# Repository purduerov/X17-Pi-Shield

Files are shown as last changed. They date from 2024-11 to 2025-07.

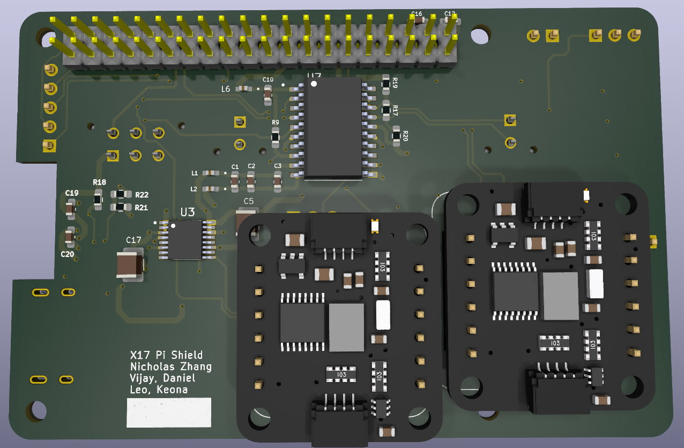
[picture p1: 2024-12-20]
Work Screenshots/3D_Back.png

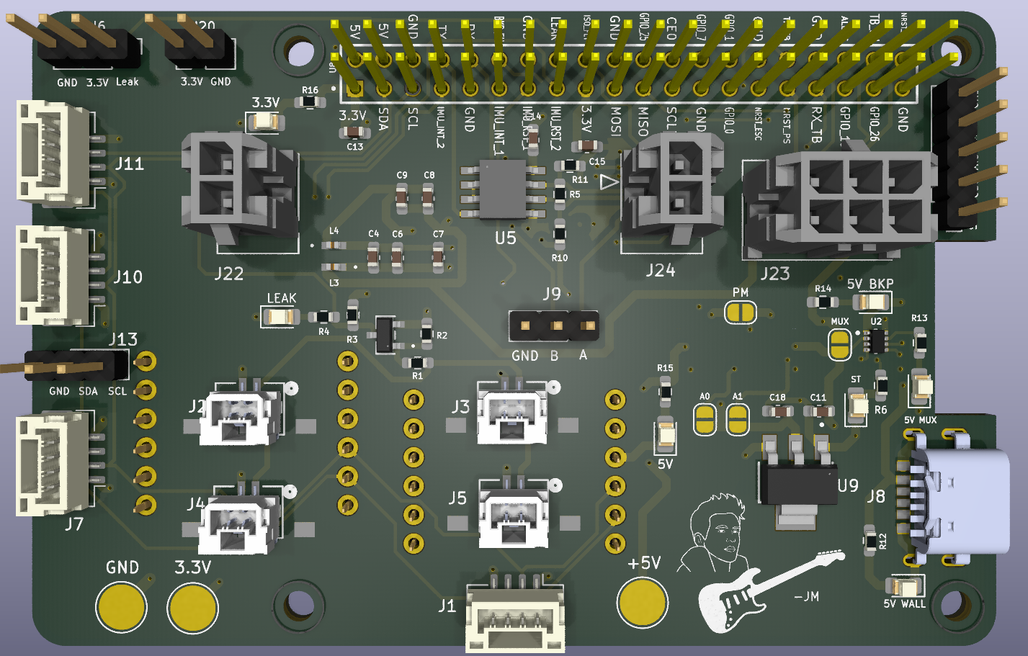
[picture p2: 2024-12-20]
Work Screenshots/3D_Front.png

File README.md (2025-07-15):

# X17-Pi-Shield
This board powers and connects sensors to the Pi

Whenever you make a new part, download the datasheet and save it here _**and**_ with the part in the parts library

Always pull other people's changes before beginning to work
`git pull`

Be sure to push your changes after  working on them. Run:
1. `git add .` to add any files in this directory or a subdirectory
or `git add -u` to add any modified files
2. (Optional) `git clean -nX` to see what ignored files can be removed
	`git clean -fX` removes ignored files (Eagle backups)
3. `git commit -m "helpful commit message"` with a description of the work that you did
4. `git push` to push your work to github

Other helpful commands
* `git status` says information about modified and staged files
* `git log` shows the recent commits of the repository
* `git log filename.extension` show the recent commits for just that file
* `git checkout first-couple-letter-of-commit-id` lets you go back to a previous version
* `git checkout master` brings you back to the latest commit
* `git tag` lists the tags
* `git tag -a orderX -m "the version of the board placed for the X'th order"` tag a specific commit
* `git push --tags` needed to push tags to remote
* `git show orderX` show the commit log for the given tag
* `git checkout orderX` go back and interact with the files at the tagged commit

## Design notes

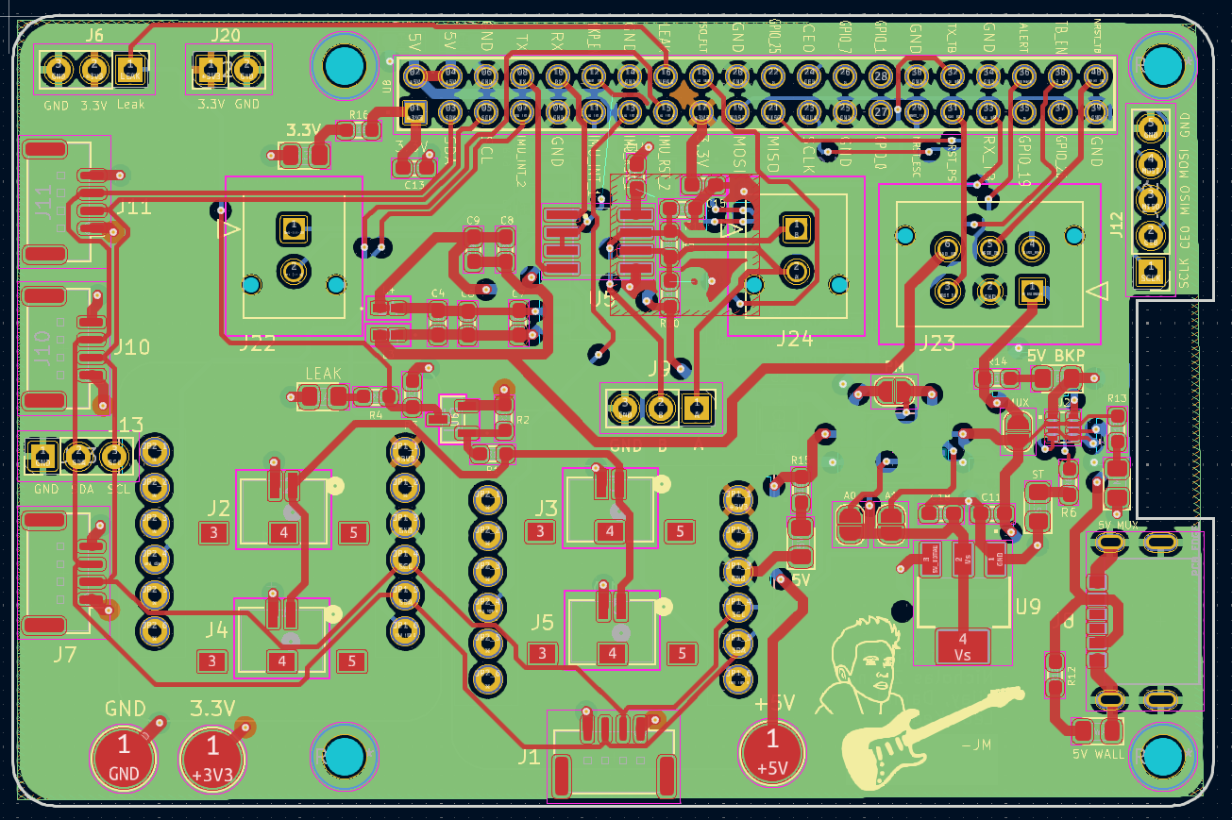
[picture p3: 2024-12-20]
Work Screenshots/Layout.png

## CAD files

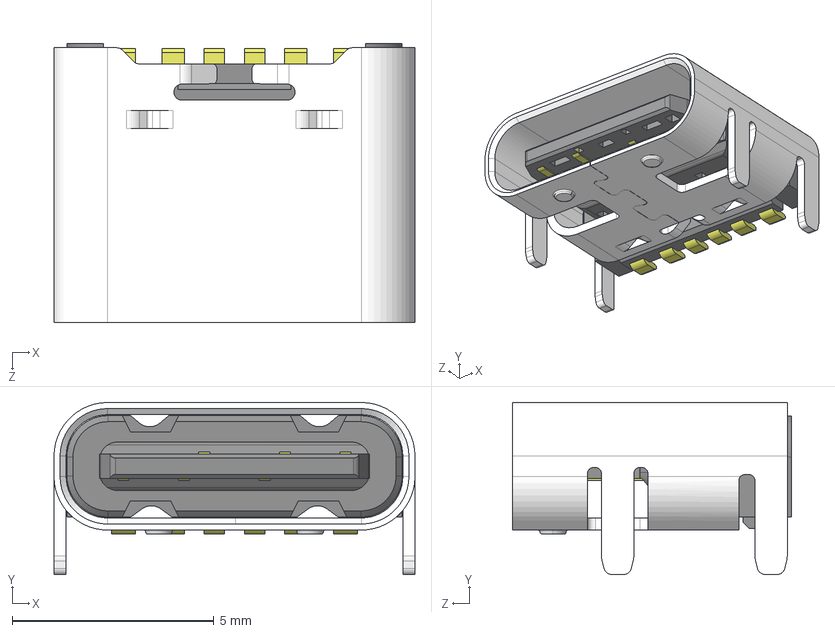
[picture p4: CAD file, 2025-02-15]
3D_MODELS/UJC-HP-3-SMT-TR.step
8.94 x 4.26 x 6.90 mm

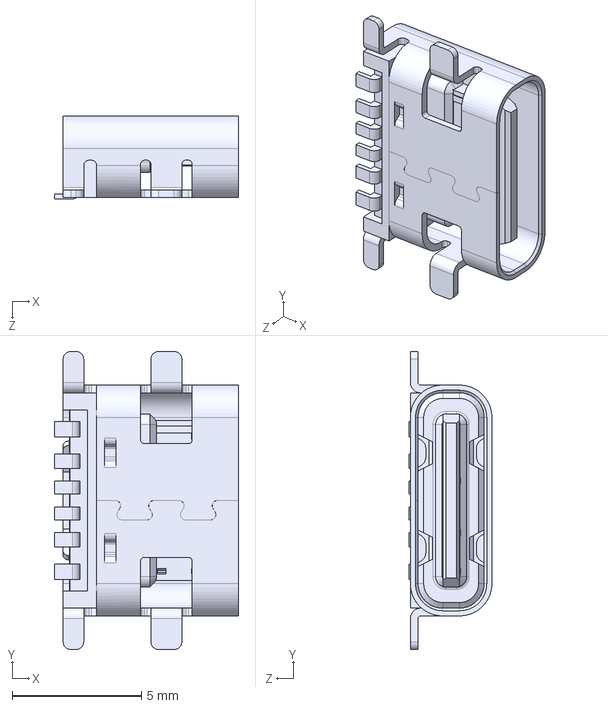
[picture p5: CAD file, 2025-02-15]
3D_MODELS/UJC-HP-G-5-SMT-TR.step
7.14 x 11.5 x 3.21 mm

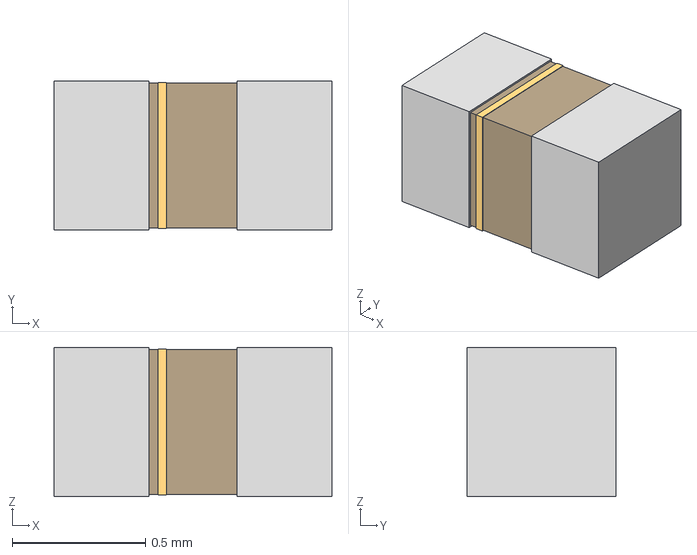
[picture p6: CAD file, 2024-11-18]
3D_MODELS/IND_BLM15_MUR.step
1.04 x 0.558 x 0.559 mm

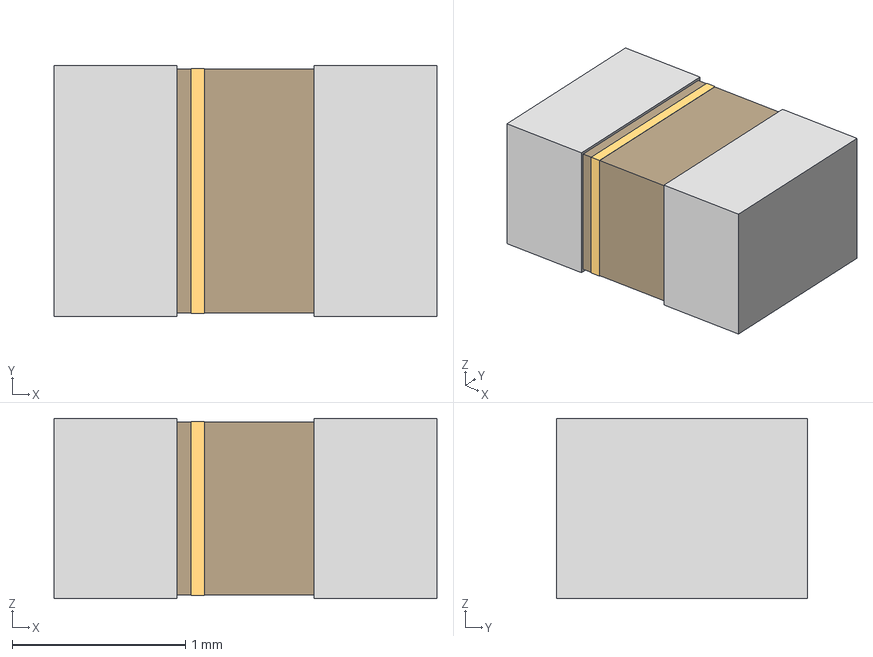
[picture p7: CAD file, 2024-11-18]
3D_MODELS/IND_BLM21_MUR.step
2.21 x 1.45 x 1.04 mm

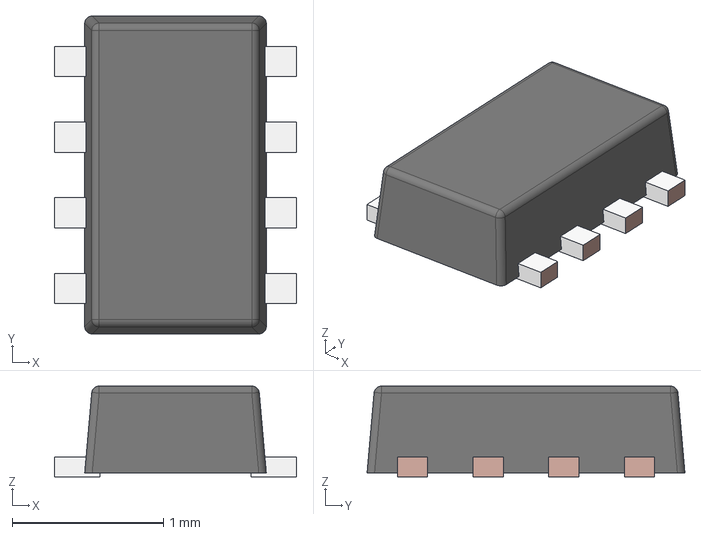
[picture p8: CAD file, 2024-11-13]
3D_MODELS/DRL0008A.stp
1.60 x 2.10 x 0.6 mm
FRAME-DRL0008A
BODY-SOT

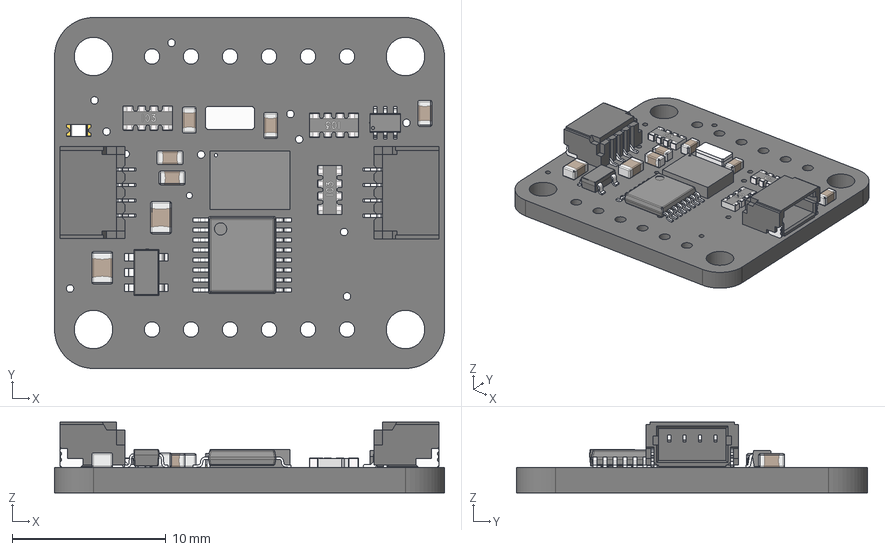
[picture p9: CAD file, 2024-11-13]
3D_MODELS/Adafruit BNO085 STEMMA QT.step
25.4 x 22.9 x 4.60 mm
Printed Circuit Board
BNO055-9axis-IMU
BNO085-9axis-IMU
BODY-TSSOP
LEAD-TSSOP x 16
Crystal_XTAL3215_32.768KHz
SOT23-5
BSS138PS
LED 0603 single color
CAPC-0805-T0.95-BN x 2
CAPC-0603-T0.9-BN x 5
YC164_RESPACK x 3
qwicc x 2

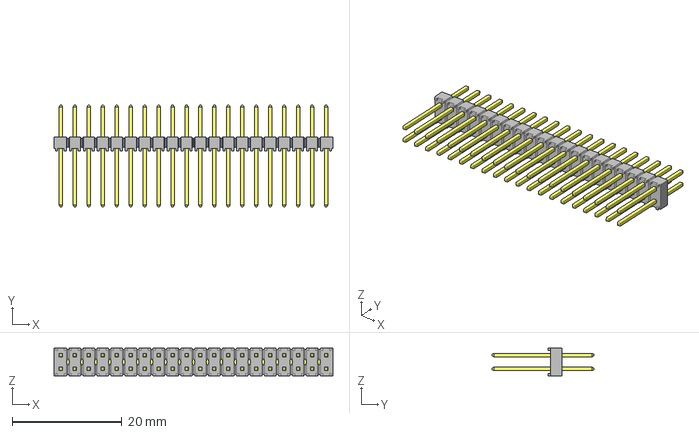
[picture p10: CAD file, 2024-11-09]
3D_MODELS/TSW-120-09-G-D.step
50.8 x 18.5 x 5.08 mm
TSW-120-09-G-D_body
T-1S6-09-TSW-1-09-20-D

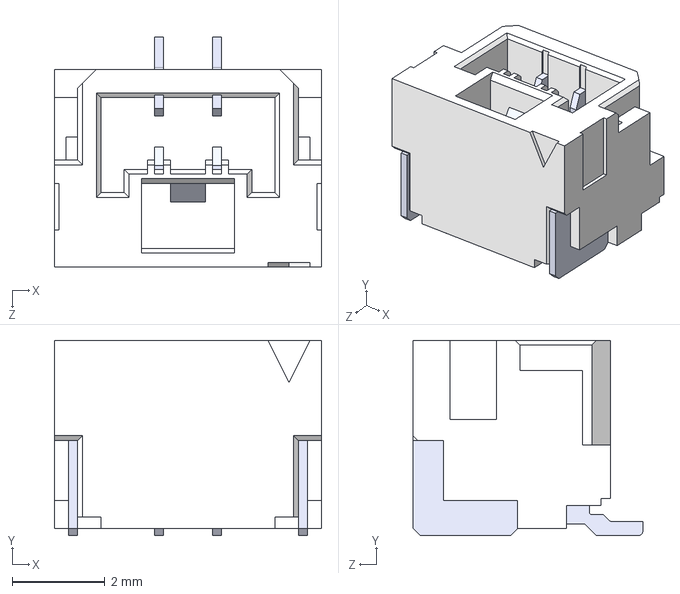
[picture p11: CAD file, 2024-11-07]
3D_MODELS/BM02B-GHS-TBT.STEP
5.75 x 4.20 x 4.95 mm

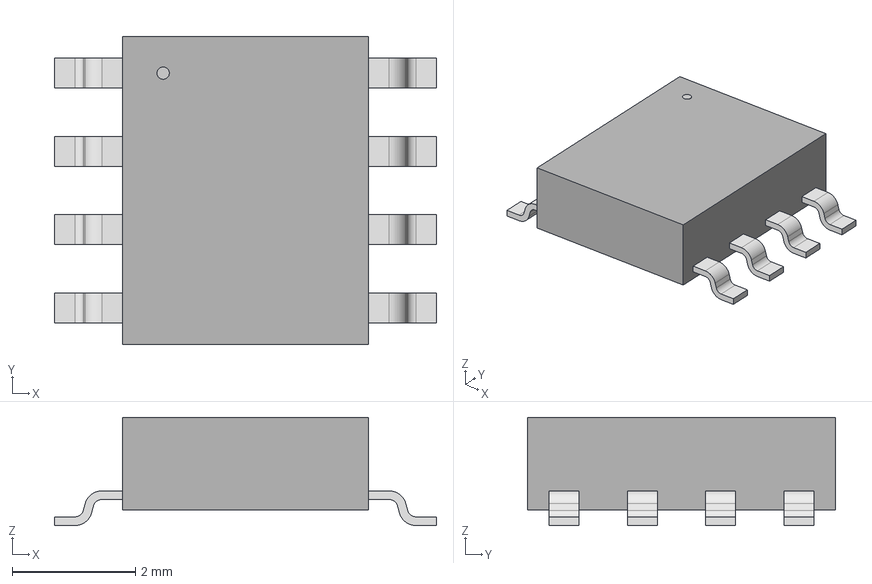
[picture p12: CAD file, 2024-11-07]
3D_MODELS/21-0041-3-M_90-0096-8L_MXM.step
6.20 x 5.00 x 1.75 mm

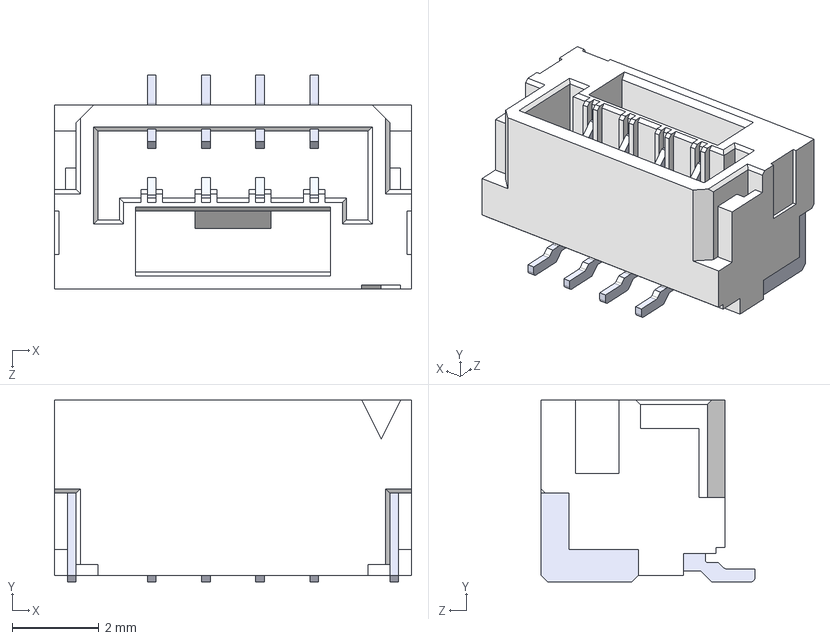
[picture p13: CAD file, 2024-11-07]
3D_MODELS/BM04B-GHS-TBT.step
8.25 x 4.20 x 4.95 mm

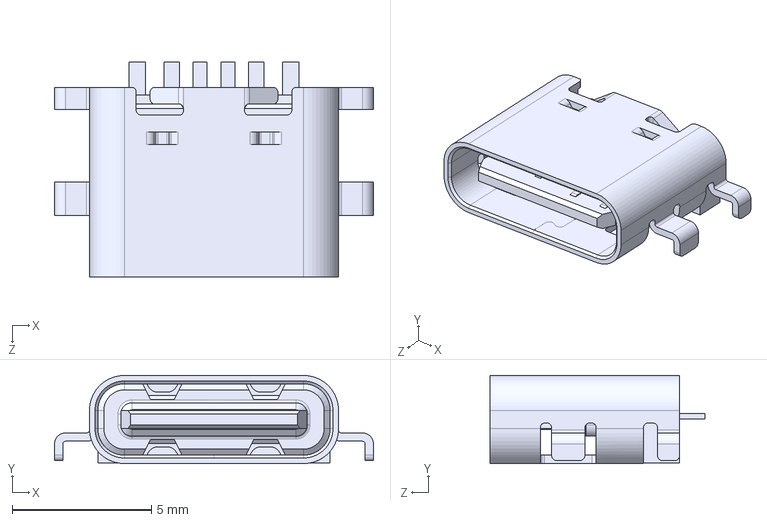
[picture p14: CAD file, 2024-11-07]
3D_MODELS/Same_Sky_UJC-HP-L-G-5-MSMT-TR.step
11.4 x 3.16 x 7.70 mm

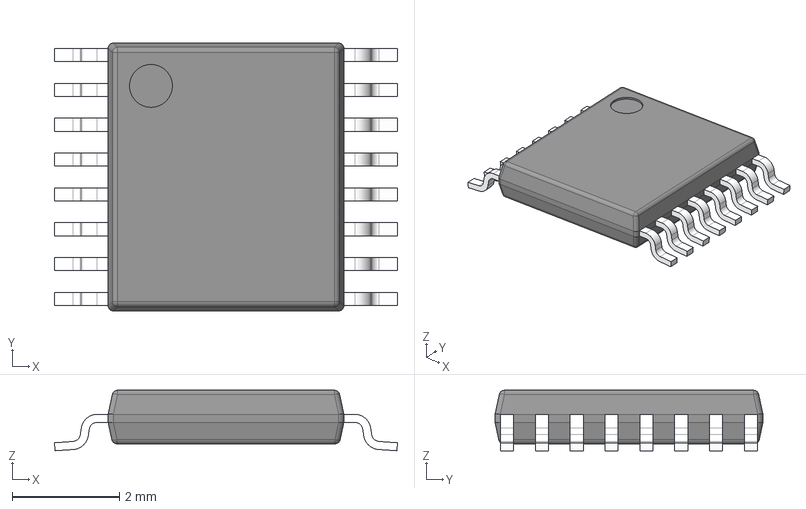
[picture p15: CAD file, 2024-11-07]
3D_MODELS/PW0016A.stp
6.40 x 5.00 x 1.13 mm
BODY-TSSOP
LEAD-TSSOP x 16
PIN1

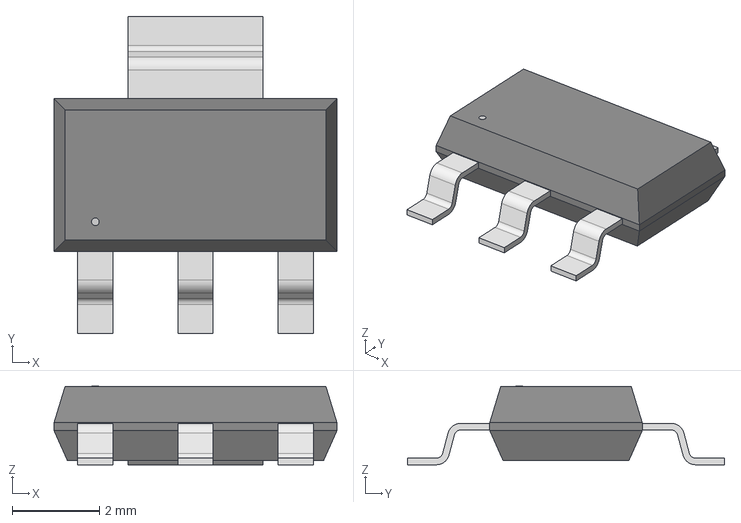
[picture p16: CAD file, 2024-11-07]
3D_MODELS/SOT223_AZ1117I_6P5X3P5_DIO.step
6.50 x 7.29 x 1.81 mm

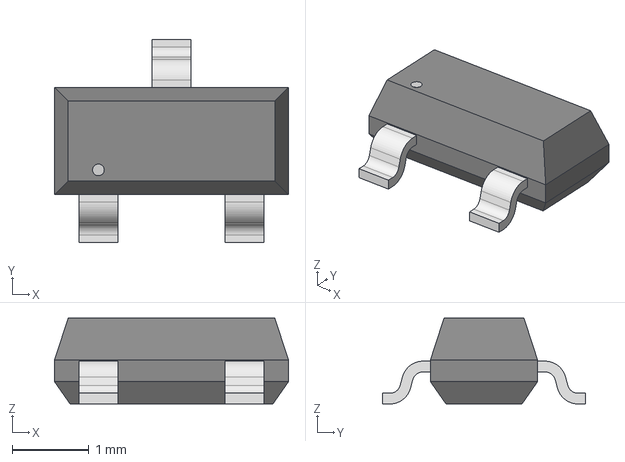
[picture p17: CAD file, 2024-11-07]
3D_MODELS/SOT-23-3_1P4X3P040_ONS.step
3.05 x 2.64 x 1.12 mm

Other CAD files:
3D_MODELS/ISOW1432BDFMR.step
3D_MODELS/INA260AIPW.step
3D_MODELS/430450212.stp
3D_MODELS/430450612.stp

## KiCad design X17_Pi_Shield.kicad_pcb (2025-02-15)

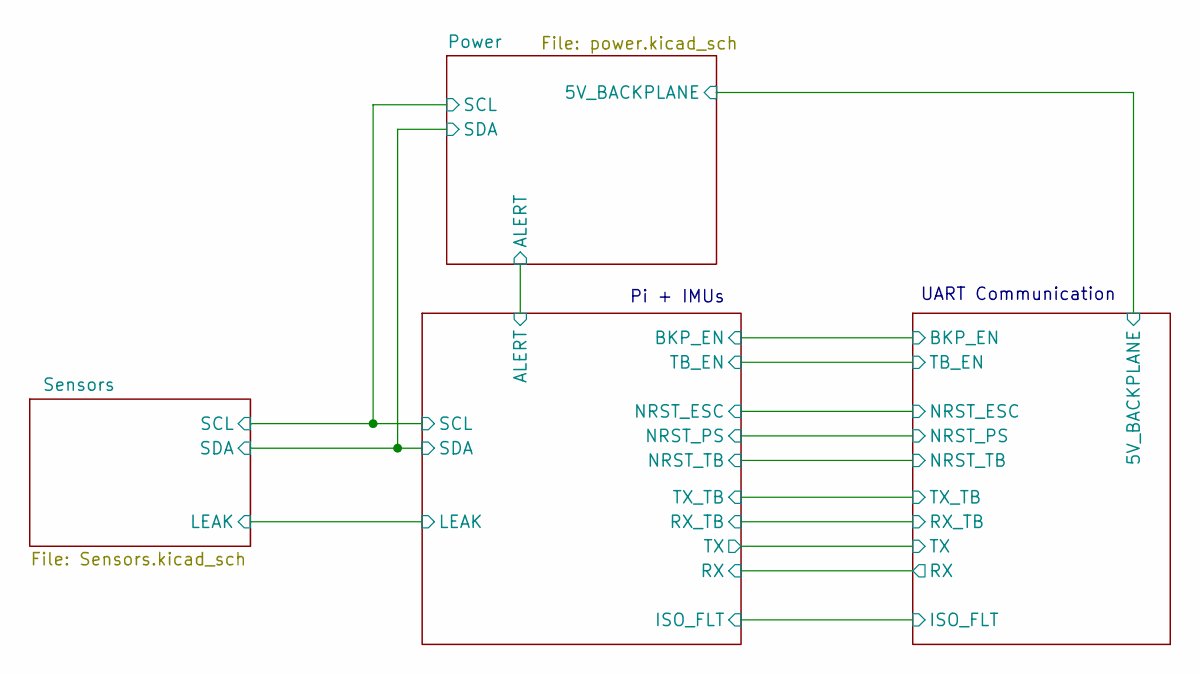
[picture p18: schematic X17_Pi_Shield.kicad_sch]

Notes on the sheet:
UART Communication
Pi + IMUs

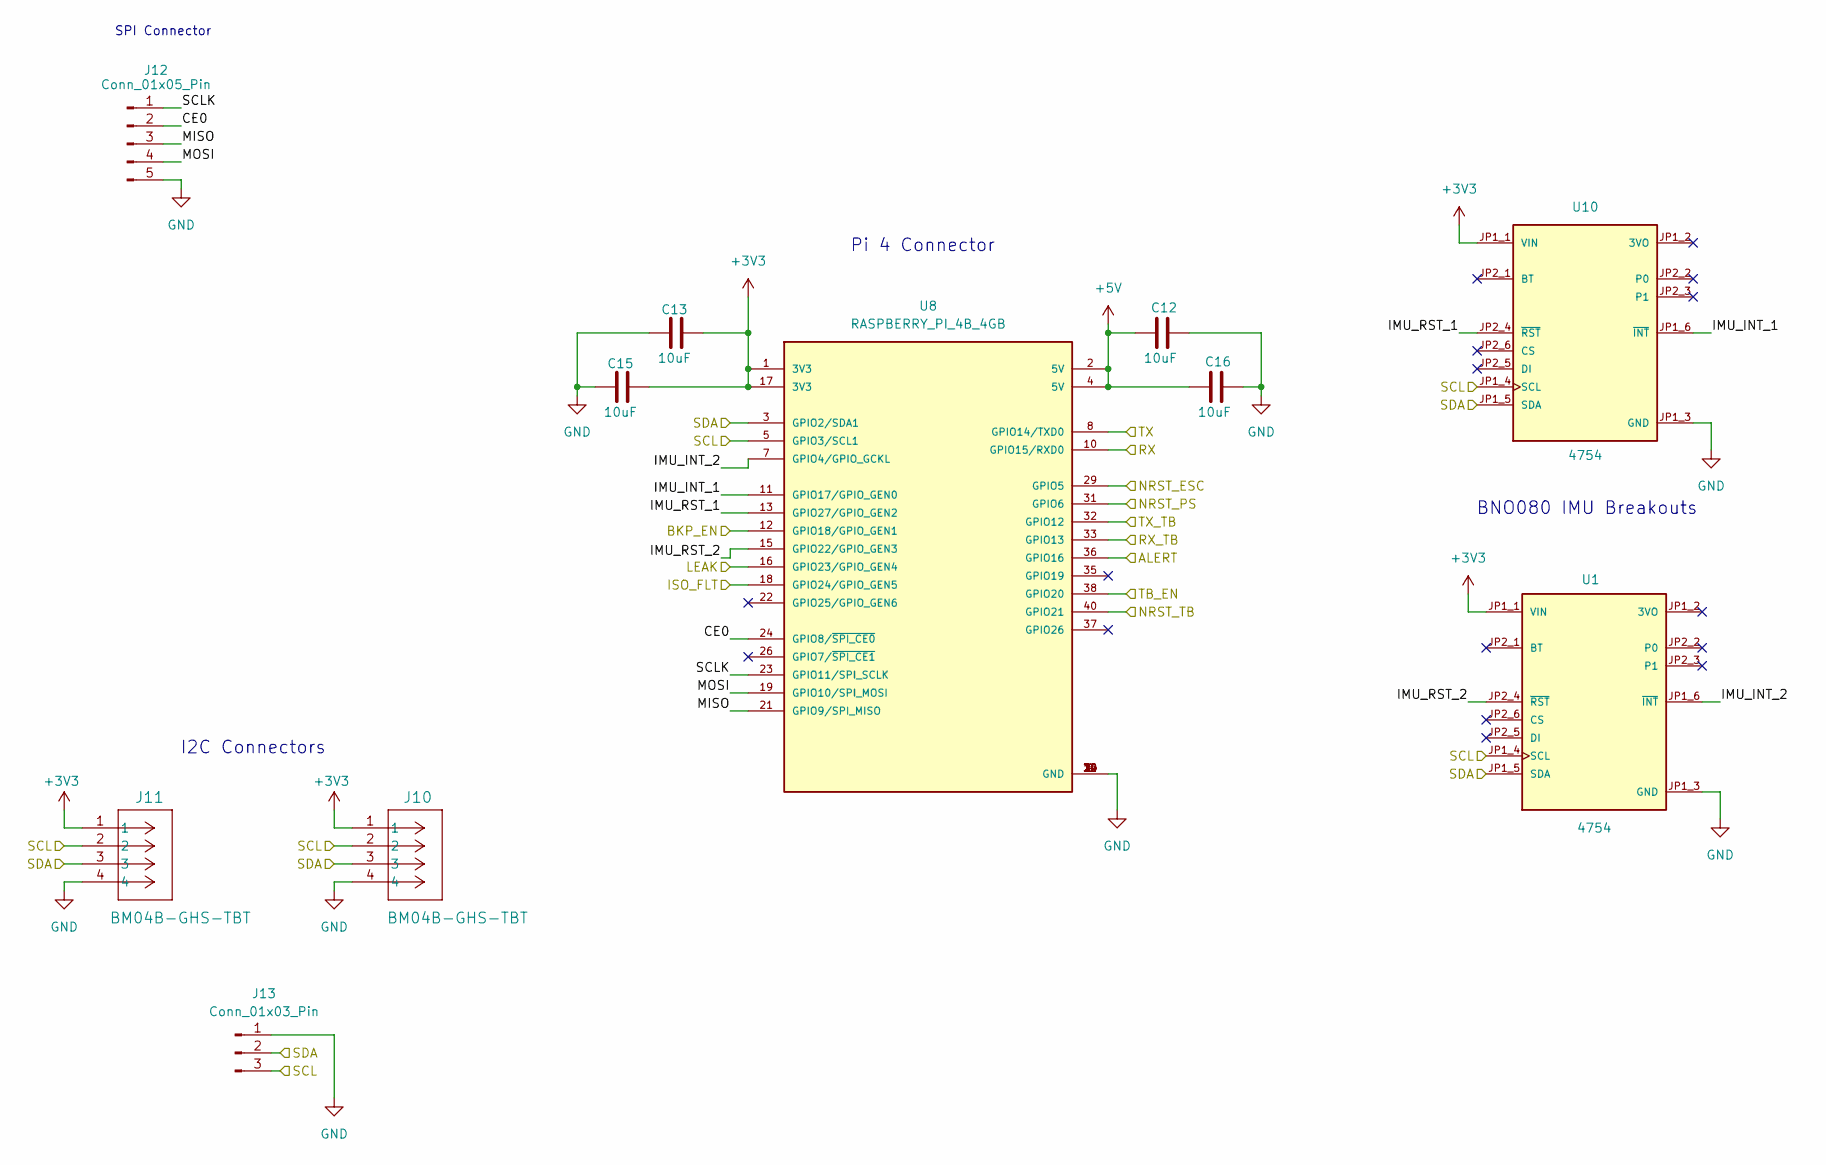
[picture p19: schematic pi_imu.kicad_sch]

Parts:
C12, C13, C15, C16: 10uF; C_0603_1608Metric_Pad1.08x0.95mm_HandSolder
J10, J11: BM04B-GHS-TBT; JST_GH_BM04B-GHS-TBT_1x04-1MP_P1.25mm_Vertical
J12: Conn_01x05_Pin; PinHeader_1x05_P2.54mm_Vertical
J13: Conn_01x03_Pin; PinHeader_1x03_P2.54mm_Vertical
U1, U10: 4754; MODULE_4754; PARTREV 2021-03-16
U8: RASPBERRY_PI_4B_4GB; SAMTEC_TSW-120-09-G-D; PARTREV 4

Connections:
+3V3: C13.1, C15.1, J10.1, J11.1, U1.JP1_1 (VIN), U8.1 (3V3), U8.17 (3V3), U10.JP1_1 (VIN); also elsewhere on the board
+5V: C12.2, C16.2, U8.2 (5V), U8.4 (5V); also elsewhere on the board
/Pi + IMU/ALERT: U8.36 (GPIO16); also elsewhere on the board
/Pi + IMU/BKP_EN: U8.12 (GPIO18/GPIO_GEN1); also elsewhere on the board
/Pi + IMU/CE0: J12.2, U8.24 (GPIO8/~SPI_CE0)
/Pi + IMU/IMU_INT_1: U8.11 (GPIO17/GPIO_GEN0), U10.JP1_6 (~INT)
/Pi + IMU/IMU_INT_2: U1.JP1_6 (~INT), U8.7 (GPIO4/GPIO_GCKL)
/Pi + IMU/IMU_RST_1: U8.13 (GPIO27/GPIO_GEN2), U10.JP2_4 (~RST)
/Pi + IMU/IMU_RST_2: U1.JP2_4 (~RST), U8.15 (GPIO22/GPIO_GEN3)
/Pi + IMU/ISO_FLT: U8.18 (GPIO24/GPIO_GEN5); also elsewhere on the board
/Pi + IMU/LEAK: U8.16 (GPIO23/GPIO_GEN4); also elsewhere on the board
/Pi + IMU/MISO: J12.3, U8.21 (GPIO9/SPI_MISO)
/Pi + IMU/MOSI: J12.4, U8.19 (GPIO10/SPI_MOSI)
/Pi + IMU/NRST_ESC: U8.29 (GPIO5); also elsewhere on the board
/Pi + IMU/NRST_PS: U8.31 (GPIO6); also elsewhere on the board
/Pi + IMU/NRST_TB: U8.40 (GPIO21); also elsewhere on the board
/Pi + IMU/RX: U8.10 (GPIO15/RXD0); also elsewhere on the board
/Pi + IMU/RX_TB: U8.33 (GPIO13); also elsewhere on the board
/Pi + IMU/SCL: J10.2, J11.2, J13.3, U1.JP1_4 (SCL), U8.5 (GPIO3/SCL1), U10.JP1_4 (SCL); also elsewhere on the board
/Pi + IMU/SCLK: J12.1, U8.23 (GPIO11/SPI_SCLK)
/Pi + IMU/SDA: J10.3, J11.3, J13.2, U1.JP1_5 (SDA), U8.3 (GPIO2/SDA1), U10.JP1_5 (SDA); also elsewhere on the board
/Pi + IMU/TB_EN: U8.38 (GPIO20); also elsewhere on the board
/Pi + IMU/TX: U8.8 (GPIO14/TXD0); also elsewhere on the board
/Pi + IMU/TX_TB: U8.32 (GPIO12); also elsewhere on the board
GND: C12.1, C13.2, C15.2, C16.1, J10.4, J11.4, J12.5, J13.1, U1.JP1_3 (GND), U8.6 (GND), U8.9 (GND), U8.14 (GND), U8.20 (GND), U8.25 (GND), U8.30 (GND), U8.34 (GND), U8.39 (GND), U10.JP1_3 (GND); also elsewhere on the board
unnamed 43: U1.JP2_5 (DI); also elsewhere on the board

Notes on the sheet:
BNO080 IMU Breakouts
I2C Connectors
SPI Connector
Pi 4 Connector

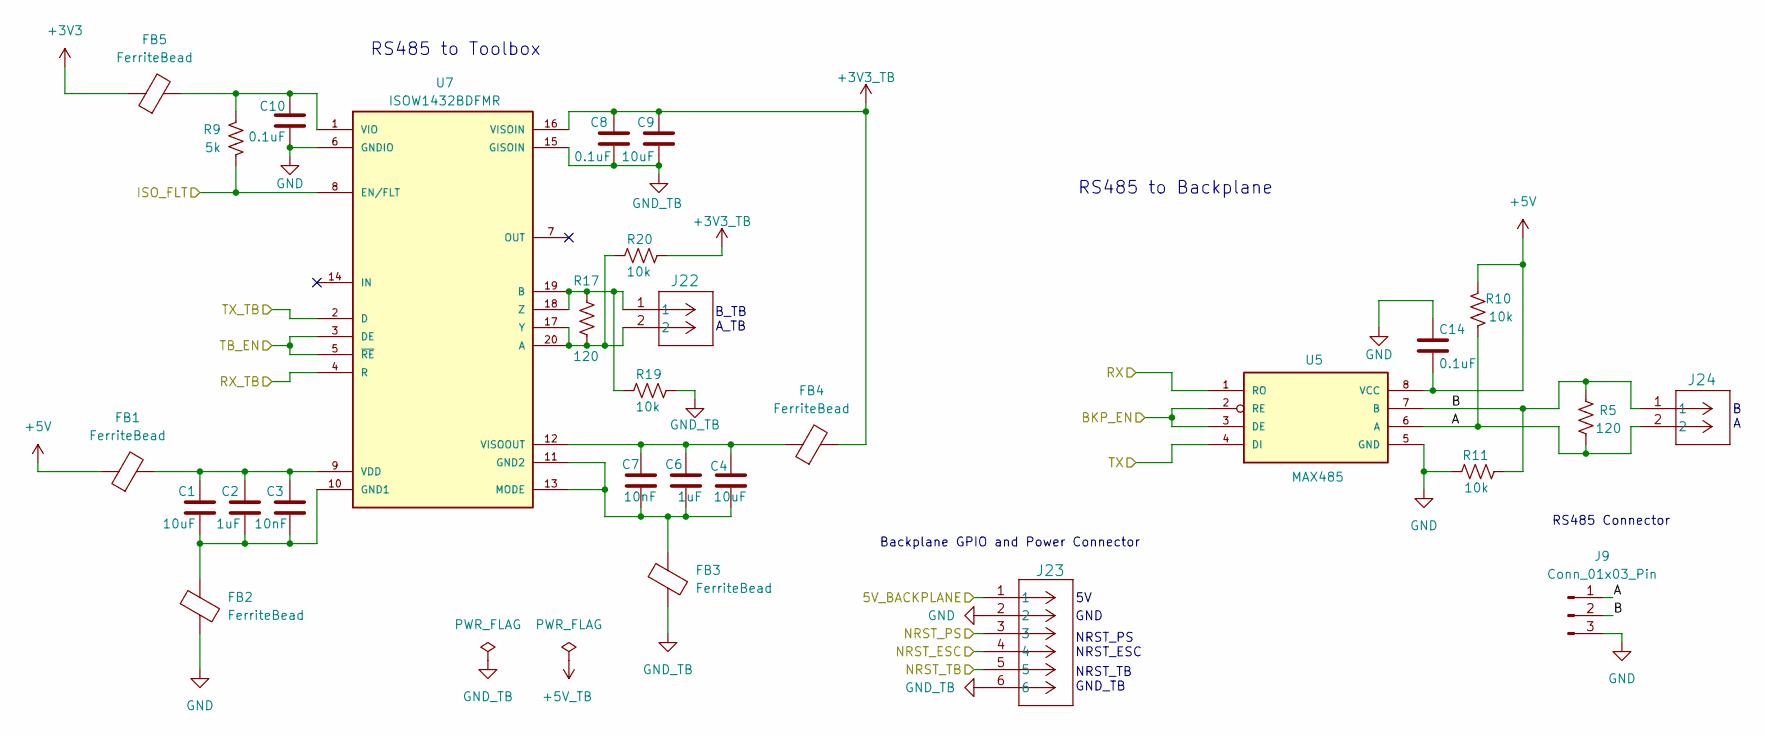
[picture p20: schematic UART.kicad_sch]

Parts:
C1, C4, C9: 10uF; C_0603_1608Metric_Pad1.08x0.95mm_HandSolder
C2, C6: 1uF; C_0603_1608Metric_Pad1.08x0.95mm_HandSolder
C3, C7: 10nF; C_0603_1608Metric_Pad1.08x0.95mm_HandSolder
C8, C10, C14: 0.1uF; C_0603_1608Metric_Pad1.08x0.95mm_HandSolder
FB1, FB2, FB3, FB4, FB5: FerriteBead; C_0603_1608Metric_Pad1.08x0.95mm_HandSolder
J9: Conn_01x03_Pin; PinHeader_1x03_P2.54mm_Vertical
J22, J24: 430450212; CON_430450212_MOL
J23: 430450612; CON_430450612_MOL
R5, R17: 120; R_0603_1608Metric_Pad0.98x0.95mm_HandSolder
R9: 5k; R_0603_1608Metric_Pad0.98x0.95mm_HandSolder
R10, R11, R19, R20: 10k; R_0603_1608Metric_Pad0.98x0.95mm_HandSolder
U5: MAX485; SO08
U7: ISOW1432BDFMR; SOIC127P1030X355-20N; PARTREV B

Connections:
+3V3: FB5.1; also elsewhere on the board
+3V3_TB: C8.1, C9.1, FB4.2, R20.2, U7.16 (VISOIN)
+5V: C14.2, FB1.1, R10.1, U5.8 (VCC); also elsewhere on the board
/Pi + IMU/BKP_EN: U5.2 (RE), U5.3 (DE); also elsewhere on the board
/Pi + IMU/ISO_FLT: R9.1, U7.8 (EN/FLT); also elsewhere on the board
/Pi + IMU/NRST_ESC: J23.4; also elsewhere on the board
/Pi + IMU/NRST_PS: J23.3; also elsewhere on the board
/Pi + IMU/NRST_TB: J23.5; also elsewhere on the board
/Pi + IMU/RX: U5.1 (RO); also elsewhere on the board
/Pi + IMU/RX_TB: U7.4 (R); also elsewhere on the board
/Pi + IMU/TB_EN: U7.3 (DE), U7.5 (~RE); also elsewhere on the board
/Pi + IMU/TX: U5.4 (DI); also elsewhere on the board
/Pi + IMU/TX_TB: U7.2 (D); also elsewhere on the board
/Power/5V_BACKPLANE: J23.1; also elsewhere on the board
/UART/A: J9.1, J24.2, R5.2, R10.2, U5.6 (A)
/UART/B: J9.2, J24.1, R5.1, R11.1, U5.7 (B)
GND: C10.1, C14.1, FB2.2, J9.3, J23.2, R11.2, U5.5 (GND), U7.6 (GNDIO); also elsewhere on the board
GND_TB: C8.2, C9.2, FB3.2, J23.6, R19.2, U7.15 (GISOIN)
unnamed: J22.2, R17.2, R20.1, U7.17 (Y), U7.20 (A)
unnamed: J22.1, R17.1, R19.1, U7.18 (Z), U7.19 (B)
unnamed: C1.2, C2.2, C3.2, FB2.1, U7.10 (GND1)
unnamed: C4.2, C6.2, C7.2, FB3.1, U7.11 (GND2), U7.13 (MODE)
unnamed: C1.1, C2.1, C3.1, FB1.2, U7.9 (VDD)
unnamed: C10.2, FB5.2, R9.2, U7.1 (VIO)
unnamed: C4.1, C6.1, C7.1, FB4.1, U7.12 (VISOOUT)

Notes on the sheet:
GND
RS485 to Backplane
B_TB A_TB
RS485 Connector
NRST_TB GND_TB
RS485 to Toolbox
B A
NRST_PS NRST_ESC
Backplane GPIO and Power Connector

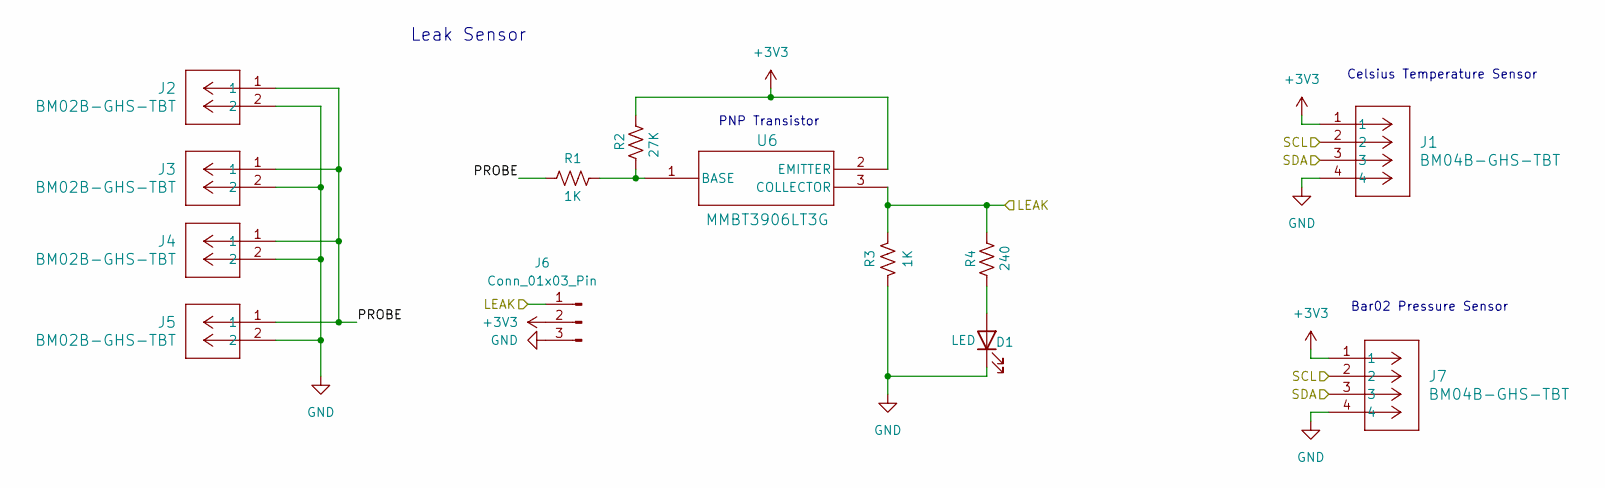
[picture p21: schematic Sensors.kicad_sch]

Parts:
D1: LED; LED_0805_2012Metric_Pad1.15x1.40mm_HandSolder
J1, J7: BM04B-GHS-TBT; JST_GH_BM04B-GHS-TBT_1x04-1MP_P1.25mm_Vertical
J2, J3, J4, J5: BM02B-GHS-TBT; CONN_BM02B-GHS-TBT_JST
J6: Conn_01x03_Pin; PinHeader_1x03_P2.54mm_Vertical
R1, R3: 1K; R_0603_1608Metric_Pad0.98x0.95mm_HandSolder
R2: 27K; R_0603_1608Metric_Pad0.98x0.95mm_HandSolder
R4: 240; R_0603_1608Metric_Pad0.98x0.95mm_HandSolder
U6: MMBT3906LT3G; SOT-23-3_1P4X3P040_ONS

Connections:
+3V3: J1.1, J6.2, J7.1, R2.2, U6.2 (EMITTER); also elsewhere on the board
/Pi + IMU/LEAK: J6.1, R3.2, R4.1, U6.3 (COLLECTOR); also elsewhere on the board
/Pi + IMU/SCL: J1.2, J7.2; also elsewhere on the board
/Pi + IMU/SDA: J1.3, J7.3; also elsewhere on the board
/Sensors/PROBE: J2.1, J3.1, J4.1, J5.1, R1.1
GND: D1.1 (K), J1.4, J2.2, J3.2, J4.2, J5.2, J6.3, J7.4, R3.1; also elsewhere on the board
unnamed: D1.2 (A), R4.2
unnamed: R1.2, R2.1, U6.1 (BASE)

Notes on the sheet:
Leak Sensor
PNP Transistor
Bar02 Pressure Sensor
Celsius Temperature Sensor

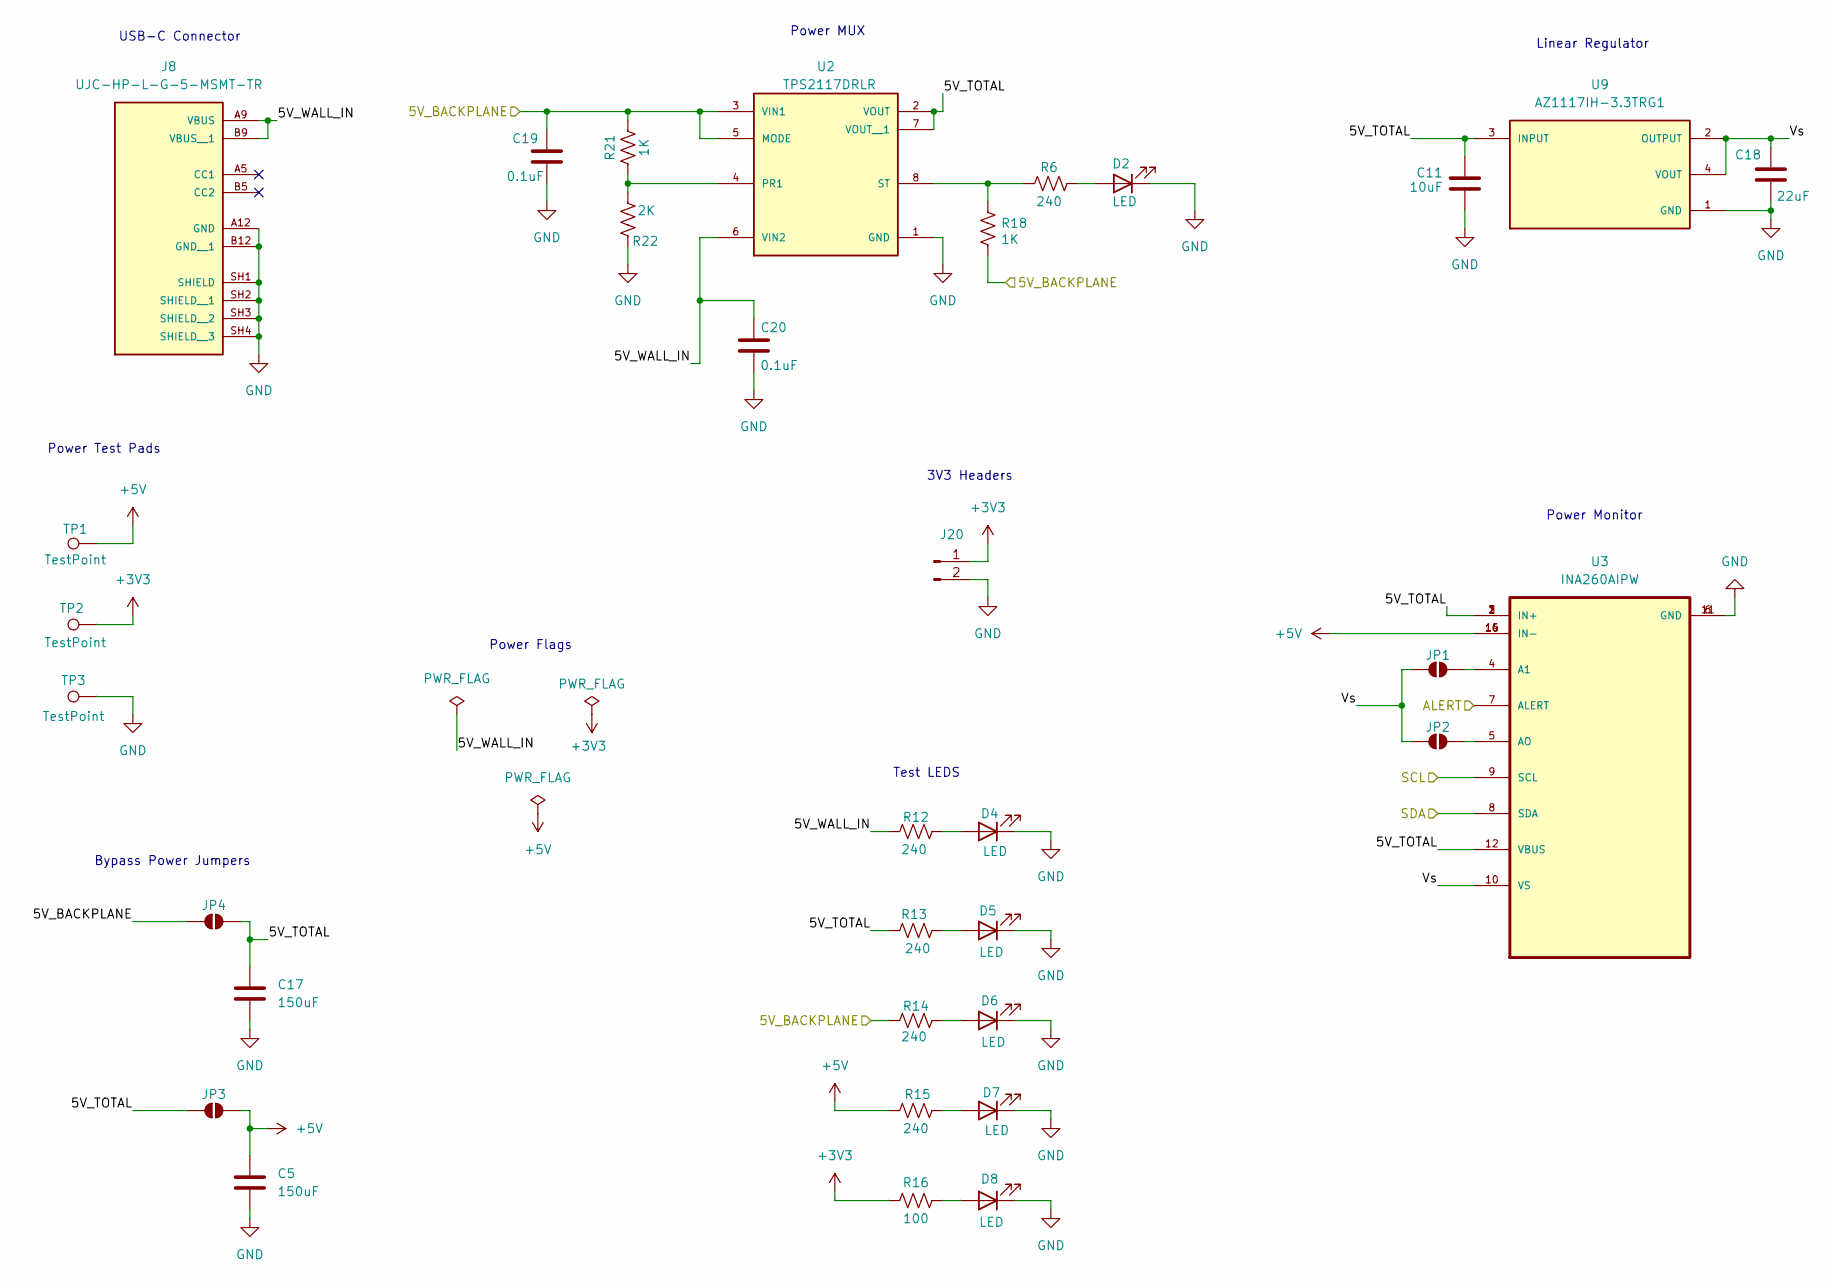
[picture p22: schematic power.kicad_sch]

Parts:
C5, C17: 150uF; C_1210_3225Metric_Pad1.33x2.70mm_HandSolder
C11: 10uF; C_0603_1608Metric_Pad1.08x0.95mm_HandSolder
C18: 22uF; C_0603_1608Metric_Pad1.08x0.95mm_HandSolder
C19, C20: 0.1uF; C_0603_1608Metric_Pad1.08x0.95mm_HandSolder
D2, D4, D5, D6, D7, D8: LED; LED_0805_2012Metric_Pad1.15x1.40mm_HandSolder
J8: UJC-HP-L-G-5-MSMT-TR; CUI_UJC-HP-L-G-5-MSMT-TR; PARTREV 1.01
J20: Conn_01x02_Pin; PinHeader_1x02_P2.54mm_Vertical
JP1, JP2, JP3, JP4: SolderJumper_2_Open; SolderJumper-2_P1.3mm_Open_RoundedPad1.0x1.5mm
R6, R12, R13, R14, R15: 240; R_0603_1608Metric_Pad0.98x0.95mm_HandSolder
R16: 100; R_0603_1608Metric_Pad0.98x0.95mm_HandSolder
R18, R21: 1K; R_0603_1608Metric_Pad0.98x0.95mm_HandSolder
R22: 2K; R_0603_1608Metric_Pad0.98x0.95mm_HandSolder
TP1, TP2, TP3: TestPoint; TestPoint_Pad_D4.0mm
U2: TPS2117DRLR; SOTFL50P160X60-8N; PARTREV A
U3: INA260AIPW; SOP65P640X120-16N
U9: AZ1117IH-3.3TRG1; SOT230P700X185-4N; PARTREV 2-2

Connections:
+3V3: J20.1, R16.1, TP2.1; also elsewhere on the board
+5V: C5.1, JP3.2 (B), R15.1, TP1.1, U3.14 (IN-), U3.15 (IN-), U3.16 (IN-); also elsewhere on the board
/Pi + IMU/ALERT: U3.7 (ALERT); also elsewhere on the board
/Pi + IMU/SCL: U3.9 (SCL); also elsewhere on the board
/Pi + IMU/SDA: U3.8 (SDA); also elsewhere on the board
/Power/5V_BACKPLANE: C19.2, JP4.1 (A), R14.1, R18.2, R21.1, U2.3 (VIN1), U2.5 (MODE); also elsewhere on the board
/Power/5V_TOTAL: C11.1, C17.1, JP3.1 (A), JP4.2 (B), R13.1, U2.2 (VOUT), U2.7 (VOUT__1), U3.1 (IN+), U3.2 (IN+), U3.3 (IN+), U3.12 (VBUS), U9.3 (INPUT)
/Power/5V_WALL_IN: C20.1, J8.A9 (VBUS), J8.B9 (VBUS__1), R12.1, U2.6 (VIN2)
/Power/Vs: C18.1, JP1.1 (A), JP2.1 (A), U3.10 (VS), U9.2 (OUTPUT), U9.4 (VOUT)
GND: C5.2, C11.2, C17.2, C18.2, C19.1, C20.2, D2.1 (K), D4.1 (K), D5.1 (K), D6.1 (K), D7.1 (K), D8.1 (K), J8.A12 (GND), J8.B12 (GND__1), J8.SH1 (SHIELD), J8.SH2 (SHIELD__1), J8.SH3 (SHIELD__2), J8.SH4 (SHIELD__3), J20.2, R22.2, TP3.1, U2.1 (GND), U3.6 (GND), U3.11 (GND), U9.1 (GND); also elsewhere on the board
unnamed: D2.2 (A), R6.2
unnamed: D4.2 (A), R12.2
unnamed: D5.2 (A), R13.2
unnamed: D6.2 (A), R14.2
unnamed: D7.2 (A), R15.2
unnamed: D8.2 (A), R16.2
unnamed: JP1.2 (B), U3.4 (A1)
unnamed: JP2.2 (B), U3.5 (AO)
unnamed: R21.2, R22.1, U2.4 (PR1)
unnamed: R6.1, R18.1, U2.8 (ST)

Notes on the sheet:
Power MUX
Power Monitor
Power Flags
3V3 Headers
Power Test Pads
USB-C Connector
Linear Regulator
Test LEDS
Bypass Power Jumpers

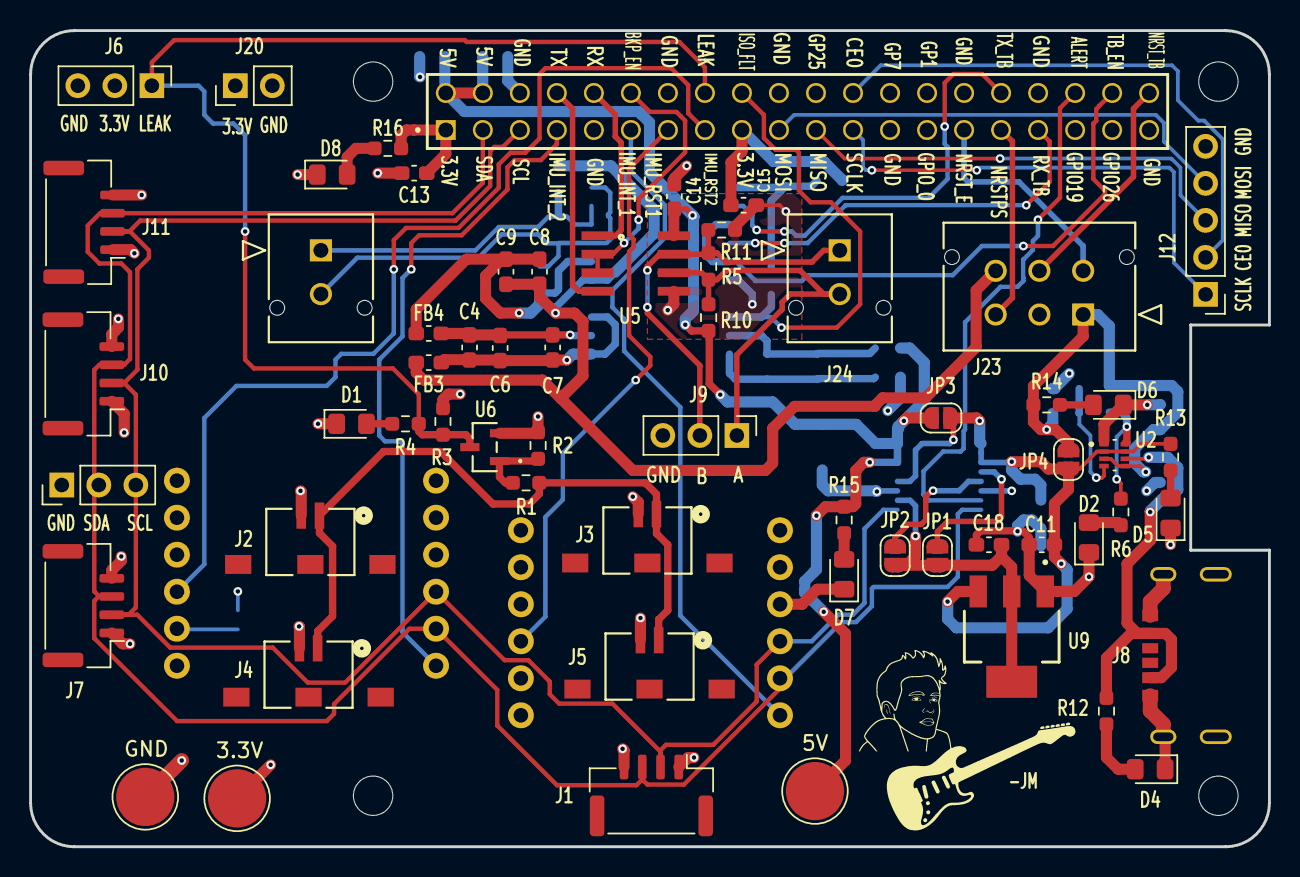
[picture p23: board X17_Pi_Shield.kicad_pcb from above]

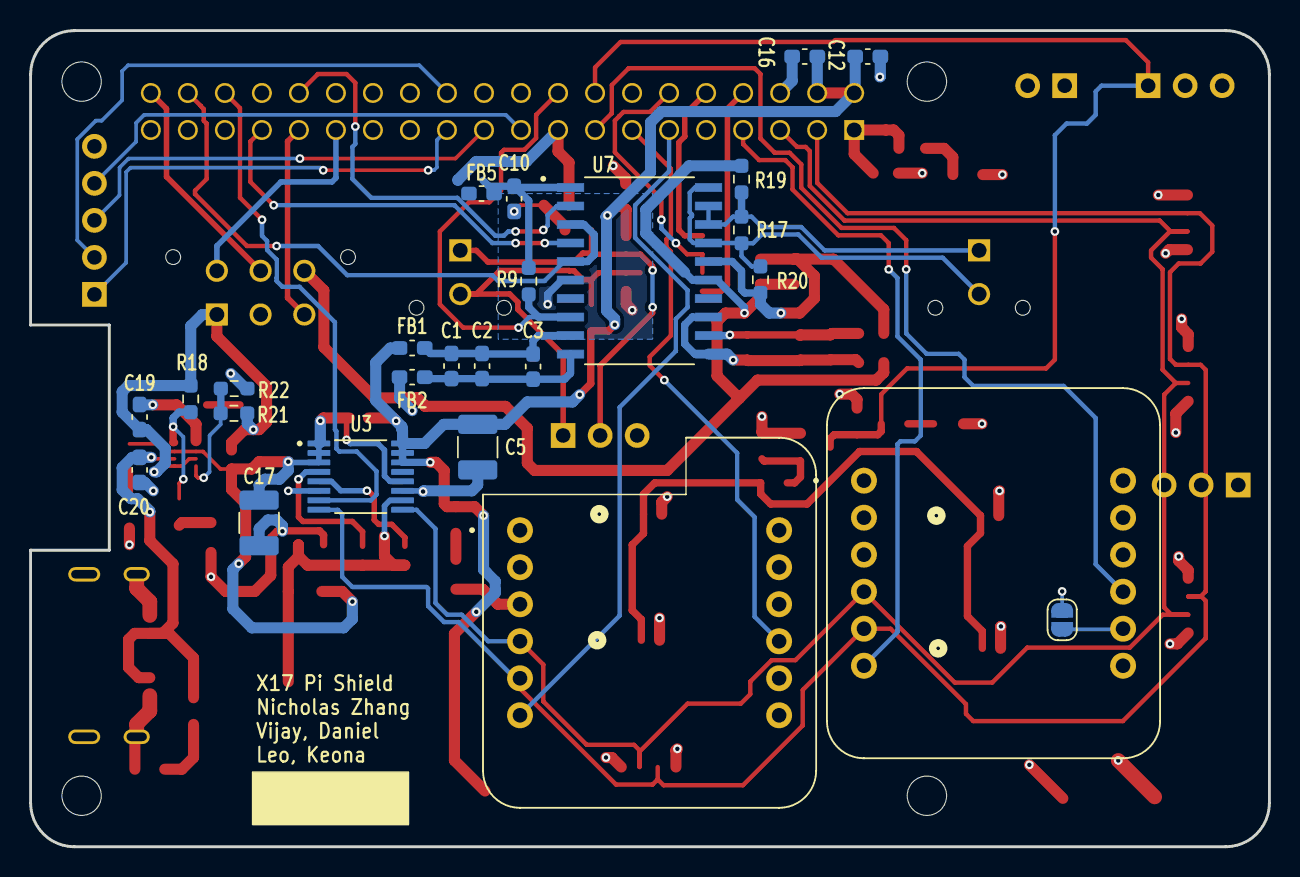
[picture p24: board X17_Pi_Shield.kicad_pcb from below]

Board: 4 copper layers, 85.0 x 56.0 mm, 86 parts (25 on the bottom side), 54 nets.

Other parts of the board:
JP5: SolderJumper_2_Open; SolderJumper-2_P1.3mm_Open_RoundedPad1.0x1.5mm

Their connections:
+3V3: JP5.1 (A); also elsewhere on the board
unnamed 43: JP5.2 (B); also elsewhere on the board

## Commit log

2024-09-25 Initial Commit: Adding KiCad files
    [X17_Pi_Shield.kicad_pcb, X17_Pi_Shield.kicad_sch]
2024-10-09 Schematic and Library Update
    [X17_Pi_Shield.kicad_sch]
2024-10-12 Hierarchy Schematic Update
    [Sensors.kicad_sch, X17_Pi_Shield.kicad_pcb, X17_Pi_Shield.kicad_sch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]
2024-10-19 Added New Libraries and Schematic Updates
    [Sensors.kicad_sch, X17_Pi_Shield.kicad_sch, pi_imu.kicad_sch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]
2024-10-22 Root Update and Adding ISO Pt1
    [Sensors.kicad_sch, UART.kicad_sch, X17_Pi_Shield.kicad_sch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]
2024-10-22 Adding Libraries
    [UART.kicad_sch, X17_Pi_Shield.kicad_pcb, X17_Pi_Shield.kicad_sch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]
2024-10-22 board dimensions
    [X17_Pi_Shield.kicad_pcb]
2024-10-23 Finalizing Schematic
    [Sensors.kicad_sch, UART.kicad_sch, X17_Pi_Shield.kicad_sch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]
2024-10-24 Final Schematic Update
    [Sensors.kicad_sch, UART.kicad_sch, X17_Pi_Shield.kicad_sch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]
2024-10-24 Updated Hiearchal Root Sheet
    [X17_Pi_Shield.kicad_sch, power.kicad_sch]
2024-10-26 Sensor Connector Update
    [UART.kicad_sch, pi_imu.kicad_sch, power.kicad_sch]
2024-11-02 Pre-Toolbox Final
    [Sensors.kicad_sch, UART.kicad_sch, X17_Pi_Shield.kicad_pcb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]
2024-11-02 re-add dimensions
    [X17_Pi_Shield.kicad_pcb]
2024-11-07 Finalized Footprints
    [Sensors.kicad_sch, UART.kicad_sch, X17_Pi_Shield.kicad_pcb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]
2024-11-07 Updating 3d Models
    [21-0041-3-M_90-0096-8L_MXM.step, 430450212.stp, 430450612.stp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]
2024-11-09 Added header and updated mounting pins
    [UART.kicad_sch, X17_Pi_Shield.kicad_pcb, pi_imu.kicad_sch]
2024-11-13 Initial Component Placement
    [DRL0008A.stp, X17_Pi_Shield.kicad_pcb, pi_imu.kicad_sch]
2024-11-14 Init Pos Workday
    [Adafruit BNO085 STEMMA QT.step, TSW-120-09-G-D.step, X17_Pi_Shield.kicad_pcb]
2024-11-19 Updated Silkscreen
    [X17_Pi_Shield.kicad_pcb]
2024-11-22 Unconnected Fix
    [X17_Pi_Shield.kicad_pcb, power.kicad_sch]
2024-11-23 Pre Design Review - Reviewed DRC Errors
    [UART.kicad_sch, X17_Pi_Shield.kicad_pcb, power.kicad_sch]
2024-12-05 Pre 4 Layer Routing
    [X17_Pi_Shield.kicad_pcb]
2024-12-15 Hello Bruh
    [UART.kicad_sch, power.kicad_sch]
2024-12-15 Routing Additions
    [X17_Pi_Shield.kicad_pcb, power.kicad_sch]
2024-12-16 Finished Routing
    [X17_Pi_Shield.kicad_pcb, pi_imu.kicad_sch, power.kicad_sch]
2024-12-17 Finished Layout + Updated Capacitor Sizes for 150uF
    [X17_Pi_Shield.kicad_pcb, power.kicad_sch]
2024-12-17 Tweaking 150uF
    [X17_Pi_Shield.kicad_pcb]
2024-12-18 Fixed MAX485 Schematic
    [UART.kicad_sch]
2024-12-18 MAX 485
    [X17_Pi_Shield.kicad_pcb]
2024-12-20 Last Updates + Adding Screenshots
    [X17_Pi_Shield.kicad_pcb]
2024-12-30 fixed several DRC errors and ferrite bead package size, still reviewing the board
    [UART.kicad_sch, X17_Pi_Shield.kicad_sch, pi_imu.kicad_sch]
2025-01-08 completed my review of pi-shield. doublechecked schematics referenced to datasheets, added solder jump to set IMU address, adjusted solder mask
    [X17_Pi_Shield.kicad_pcb]
2025-01-10 all files added
    [X17_Pi_Shield-B_Cu.gbl, X17_Pi_Shield-B_Mask.gbs, X17_Pi_Shield-B_Paste.gbp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]
2025-02-15 Fixed Silkscreen orientation/ USB-C 3d Model
    [UJC-HP-3-SMT-TR.step, UJC-HP-G-5-SMT-TR.step, X17_Pi_Shield.kicad_pcb]

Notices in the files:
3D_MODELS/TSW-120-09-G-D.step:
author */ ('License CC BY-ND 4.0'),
